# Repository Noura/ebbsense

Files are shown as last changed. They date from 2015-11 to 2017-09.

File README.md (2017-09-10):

# EBB Sense
  Controlling a wearable display using a bitalino EDA sensor

### Software
- Arduino Code

### Serial Graph for Debugging
- Graph the data from the arduino code running over Serial port
- Scale using up and down keys

### Hardware

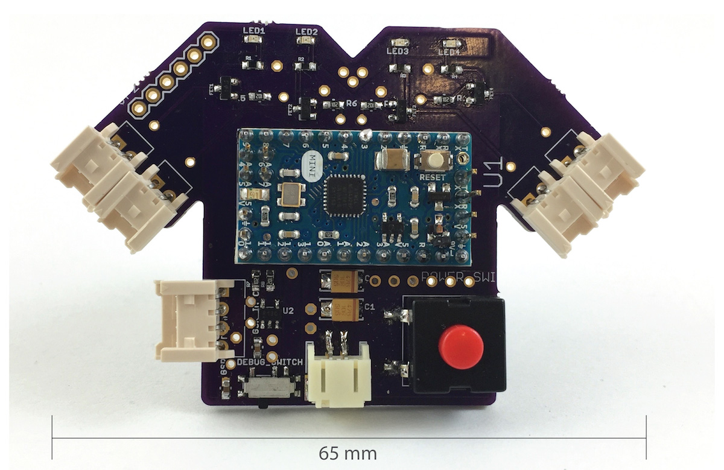
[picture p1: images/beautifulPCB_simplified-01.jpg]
Custom PCB


- Eagle schematic and board
- Current version is 2.1

### Shirt

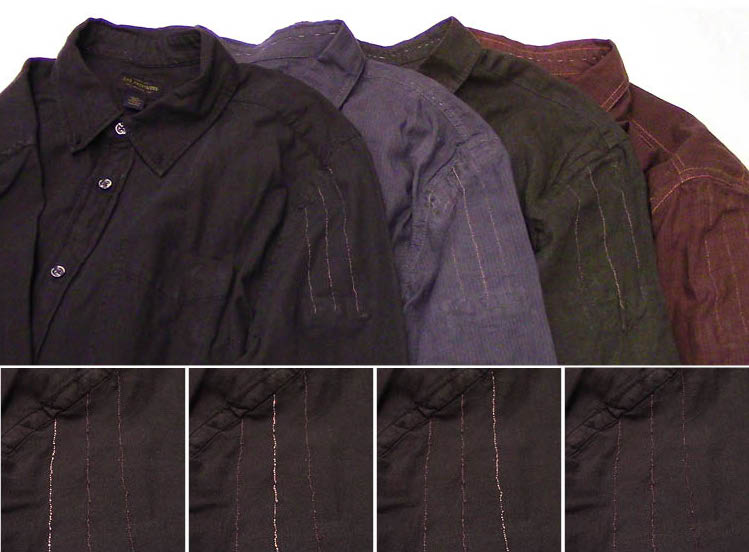
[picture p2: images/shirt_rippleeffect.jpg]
Shirt


Each pinstripe had about 2-7Ω resistance and received about 450mA from a 3.7V LiPo battery via an Adafruit Powerboost 5V regulator, switching on (100% duty cycle) or off (0%) with a transistor controlled by Arduino pins. Each pinstripe consists of a single conductive thread. Snaps on the inside of the shirt provided removable but secure electrical connections to the thread endpoints. A Bitalino skin conductance sensor was placed on the back of the left shoulder of the shirt to hide the sensor from public view and secure it within the shirt. 

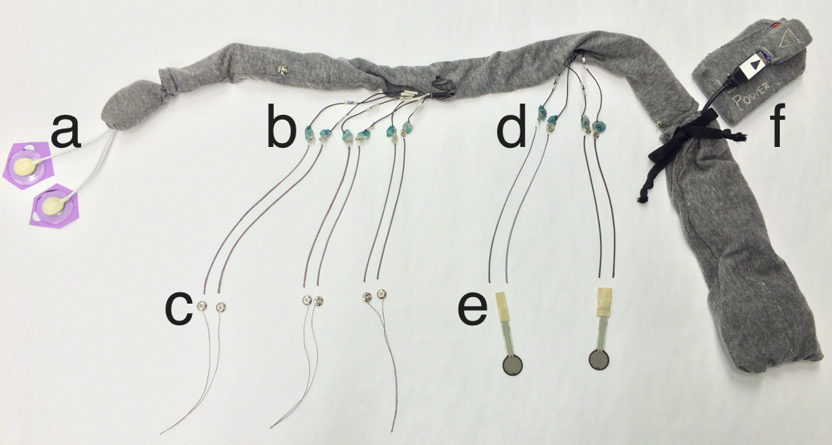
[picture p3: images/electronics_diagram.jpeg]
Electronics Physical Diagram


Fabric enclosures for electronics fit inside the shirt. (a) Skin conductance sensor with electrodes on colored paper for visibility. (b) Snaps connections to pinstripes. (c) Diagrammatic representation of pinstripes, which in actuality were sewn into shirt. (d) Snaps connections with FSRs for override on/off features. (e) Diagrammatic representation of FSRs, which in actuality were embedded in shirt seams. (f) PCB and battery, which were hidden in an interior shirt pocket.

---

### Team
- Noura Howell
- Laura Devendorf
- Rundong Tian
- Tomás Vega

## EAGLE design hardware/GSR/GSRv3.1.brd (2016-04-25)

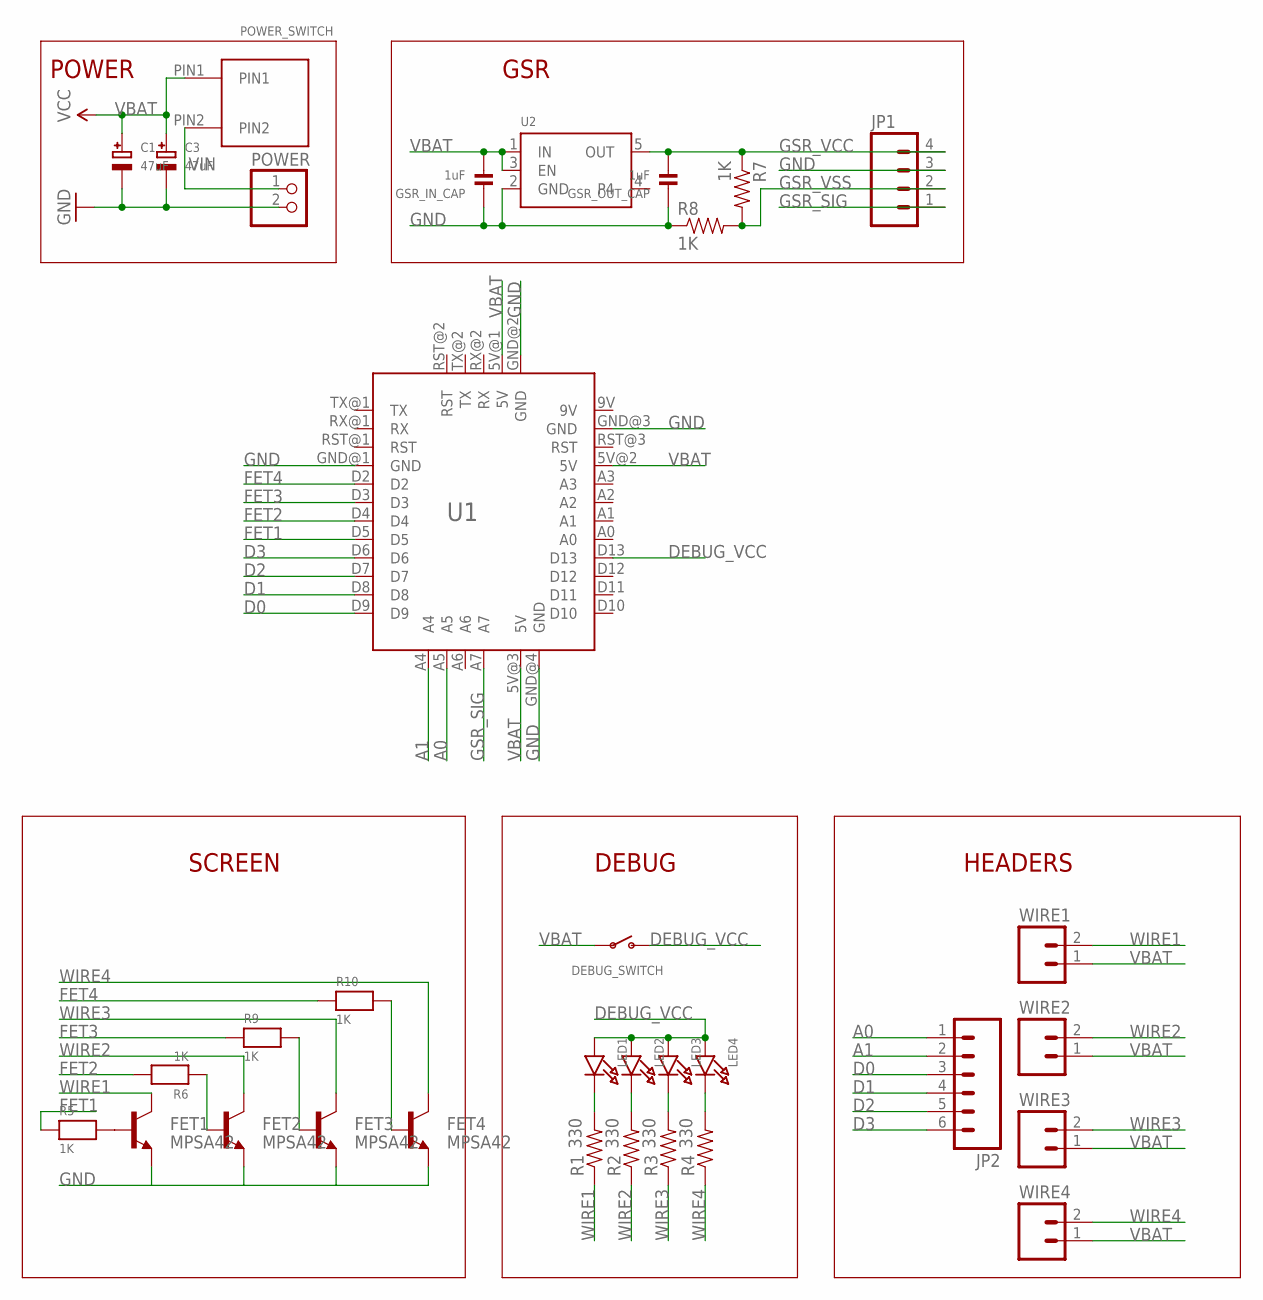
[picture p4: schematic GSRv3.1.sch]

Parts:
C1, C3: 47uF; EIA3528-21/B-W
DEBUG_SWITCH: SWITCH_SPST; SPST_SMT_19192
FET1, FET2, FET3, FET4: MPSA42; SOT23-3
GSR_IN_CAP: 1uF; 0603
GSR_OUT_CAP: 1uF; 0603
JP1: M04POLAR; MOLEX-1X4
JP2: M06SILK_FEMALE_PTH; 1X06
LED1, LED2, LED3, LED4: LED0603_NOOUTLINE; CHIPLED_0603_NOOUTLINE
POWER: JST_2PIN; JSTPH2
POWER_SWITCH: PUSH_BUTTON
R1, R2, R3, R4: 330; 0603-RES
R5, R6, R7, R8, R9, R10: 1K; 0603
U1: ARDUINO_MINI
U2: VREG_SOT23-5; SOT23-5
WIRE1, WIRE2, WIRE3, WIRE4: M02POLAR; MOLEX-1X2

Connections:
9V: U1.9V
A0: JP2.1, U1.A5
A1: JP2.2, U1.A4
D0: JP2.3, U1.D9
D1: JP2.4, U1.D8
D2: JP2.5, U1.D7
D3: JP2.6, U1.D6
DEBUG_VCC: DEBUG_SWITCH.C (S), LED1.A, LED2.A, LED3.A, LED4.A, U1.D13
FET1: R5.1, U1.D5
FET2: R6.2, U1.D4
FET3: R9.1, U1.D3
FET4: R10.1, U1.D2
GND: C1.-, C3.-, FET1.2 (E), FET2.2 (E), FET3.2 (E), FET4.2 (E), GSR_IN_CAP.1, GSR_OUT_CAP.1, JP1.3, POWER.2, R8.1, U1.GND@1 (GND), U1.GND@2 (GND), U1.GND@3 (GND), U1.GND@4 (GND), U2.2 (GND)
GSR_SIG: JP1.1, U1.A7
GSR_VCC: GSR_OUT_CAP.2, JP1.4, R7.1, U2.5 (OUT)
GSR_VSS: JP1.2, R7.2, R8.2
unnamed: LED1.C, R1.2
unnamed: LED2.C, R2.2
unnamed: LED3.C, R3.2
unnamed: LED4.C, R4.2
unnamed: FET1.1 (B), R5.2
unnamed: FET2.1 (B), R6.1
unnamed: FET3.1 (B), R9.2
unnamed: FET4.1 (B), R10.2
VBAT: C1.+, C3.+, DEBUG_SWITCH.B, GSR_IN_CAP.2, POWER_SWITCH.PIN1, U1.5V@1 (5V), U1.5V@2 (5V), U1.5V@3 (5V), U2.1 (IN), U2.3 (EN), WIRE1.1, WIRE2.1, WIRE3.1, WIRE4.1
VIN: POWER.1, POWER_SWITCH.PIN2
WIRE1: FET1.3 (C), R1.1, WIRE1.2
WIRE2: FET2.3 (C), R2.1, WIRE2.2
WIRE3: FET3.3 (C), R3.1, WIRE3.2
WIRE4: FET4.3 (C), R4.1, WIRE4.2

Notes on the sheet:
DEBUG
SCREEN
HEADERS
POWER
GSR

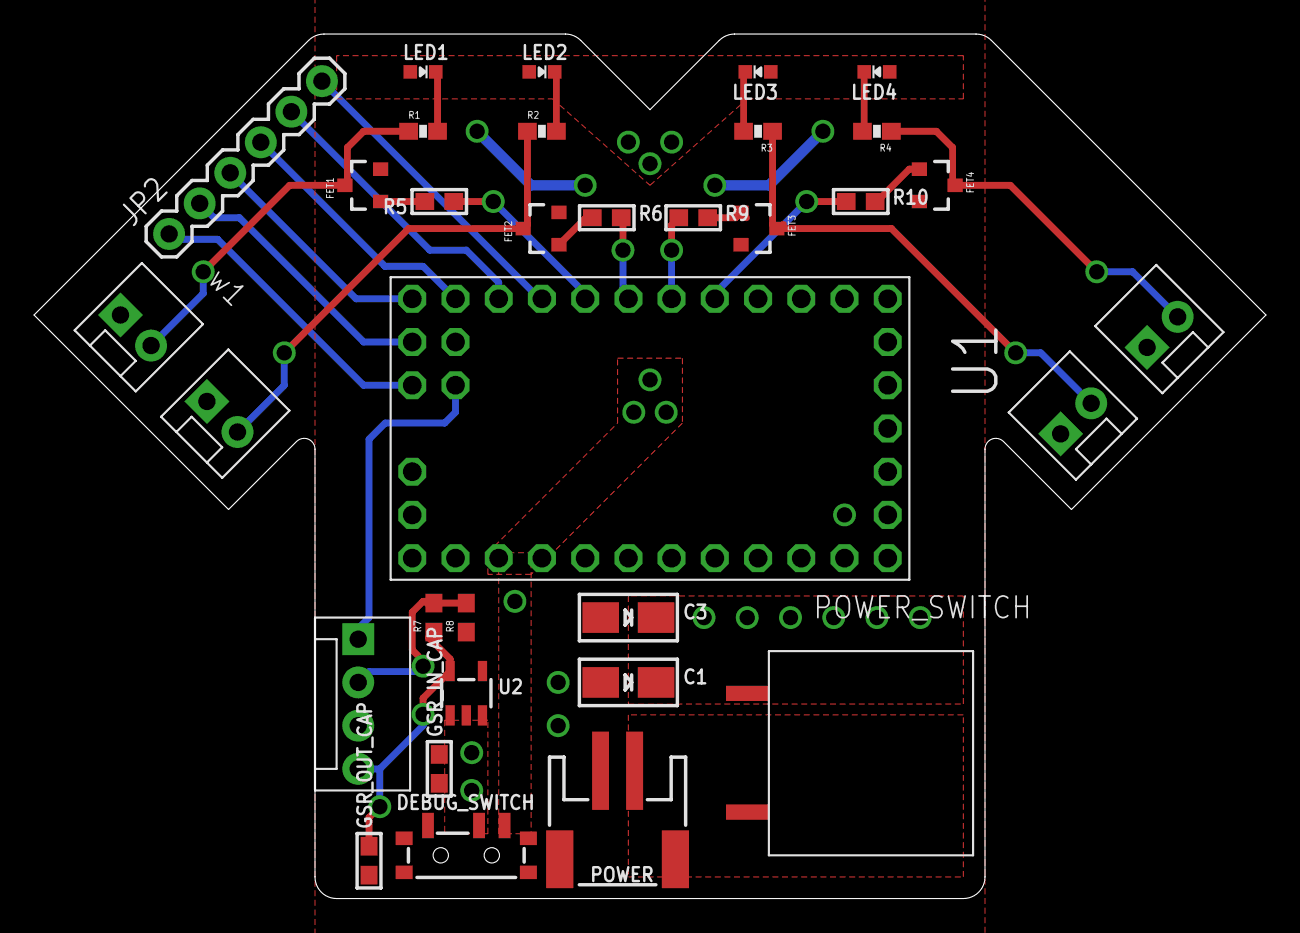
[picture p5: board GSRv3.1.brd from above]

Board: 2 copper layers, 72.4 x 50.8 mm, 33 parts (0 on the bottom side), 29 nets.

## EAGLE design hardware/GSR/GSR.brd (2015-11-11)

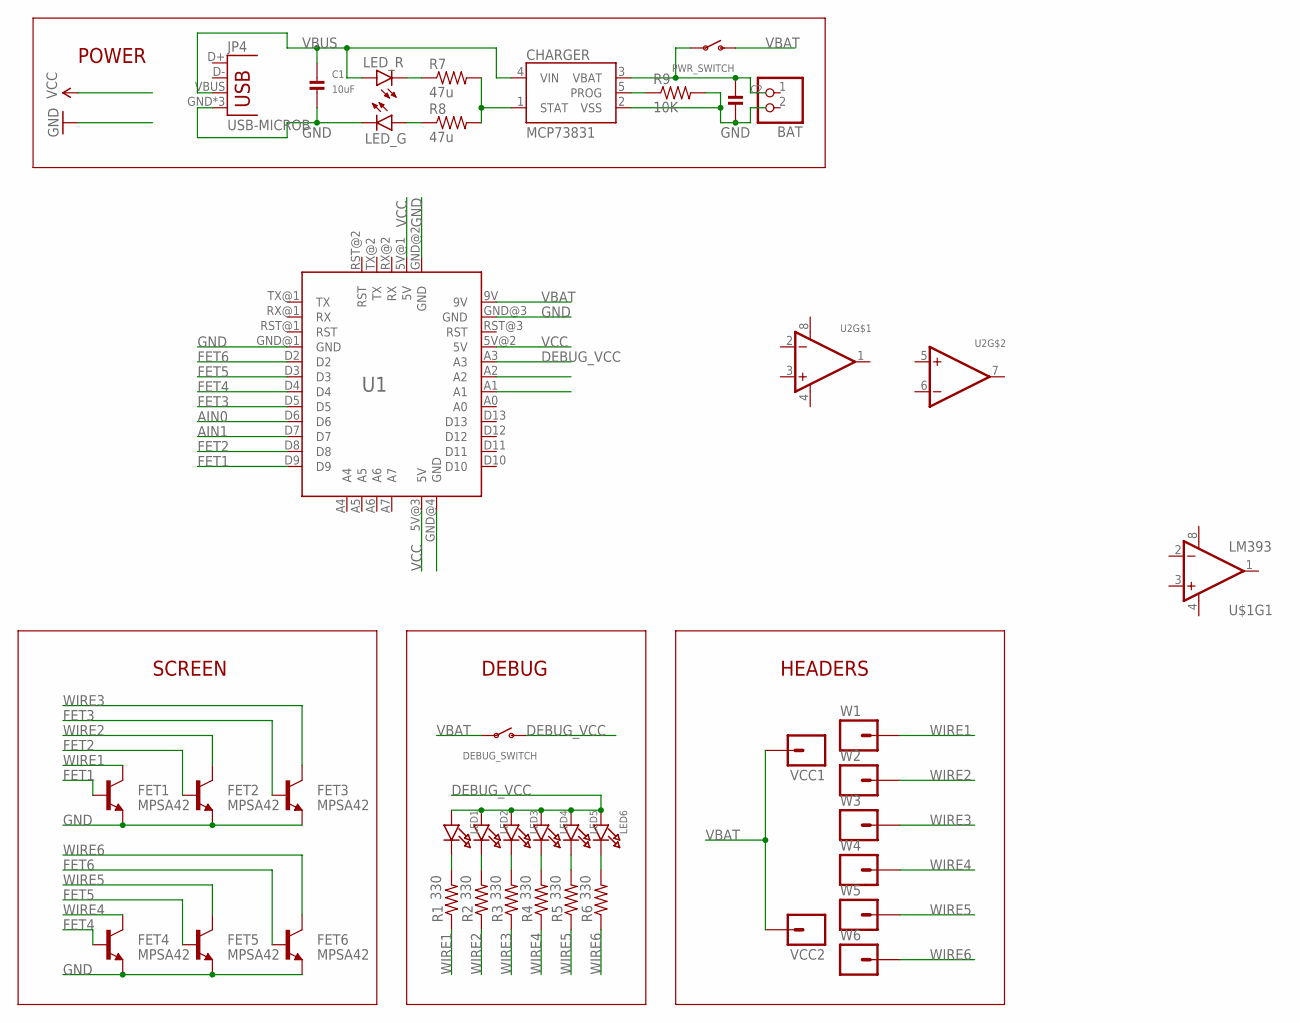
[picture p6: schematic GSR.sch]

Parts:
BAT: JST_2PIN-SMT; JST-PH-2-SMT
C1: 10uF; 0603
C2: CAP_CERAMIC0603; 0603
CHARGER: MCP73831; SOT23-5
DEBUG_SWITCH: SWITCH_SPST; SPST_SMT_19192
FET1, FET2, FET3, FET4, FET5, FET6: MPSA42; SOT23-3
JP4: USB-MICROB
LED1, LED2, LED3, LED4, LED5, LED6: LED0603_NOOUTLINE; CHIPLED_0603_NOOUTLINE
LED_G: LED0603; LED-0603
LED_R: LED0603; LED-0603
PWR_SWITCH: SWITCH_SPST; SPST_SMT_19192
R1, R2, R3, R4, R5, R6: 330; 0603-RES
R7, R8: 47u; 0603-RES
R9: 10K; 0603-RES
U1: ARDUINO_MINI
U2: OPAMP_DUALMSOP8_65; MSOP8_0.65MM
U$1: LM393; SO08
VCC1, VCC2: M01NOSILK-KIT; 1X01NS-KIT
W1, W2, W3, W4, W5, W6: M01NOSILK-KIT; 1X01NS-KIT

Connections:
AIN0: U1.D6
AIN1: U1.D7
DEBUG_VCC: DEBUG_SWITCH.C (S), LED1.A, LED2.A, LED3.A, LED4.A, LED5.A, LED6.A, U1.A3
FET1: FET1.1 (B), U1.D9
FET2: FET2.1 (B), U1.D8
FET3: FET3.1 (B), U1.D5
FET4: FET4.1 (B), U1.D4
FET5: FET5.1 (B), U1.D3
FET6: FET6.1 (B), U1.D2
GND: C1.2, C2.2, CHARGER.2 (VSS), FET1.2 (E), FET2.2 (E), FET3.2 (E), FET4.2 (E), FET5.2 (E), FET6.2 (E), JP4.GND, JP4.MT1 (GND), JP4.MT2 (GND), LED_G.C, R9.2, U1.GND@1 (GND), U1.GND@2 (GND), U1.GND@3 (GND), U1.GND@4 (GND)
unnamed: LED1.C, R1.2
unnamed: LED2.C, R2.2
unnamed: LED3.C, R3.2
unnamed: LED4.C, R4.2
unnamed: LED5.C, R5.2
unnamed: LED6.C, R6.2
unnamed: CHARGER.1 (STAT), R7.2, R8.2
unnamed: LED_G.A, R8.1
unnamed: LED_R.C, R7.1
unnamed: CHARGER.5 (PROG), R9.1
V+: U2.8 (V+), U$1.8 (V+)
V-: U2.4 (V-), U$1.4 (V-)
VBAT: DEBUG_SWITCH.B, PWR_SWITCH.C (S), U1.9V, VCC1.1, VCC2.1
VBAT_IN: C2.1, CHARGER.3 (VBAT), PWR_SWITCH.B
VBUS: C1.1, CHARGER.4 (VIN), JP4.VBUS, LED_R.A
VCC: U1.5V@1 (5V), U1.5V@2 (5V), U1.5V@3 (5V)
WIRE1: FET1.3 (C), R1.1, W1.1
WIRE2: FET2.3 (C), R2.1, W2.1
WIRE3: FET3.3 (C), R3.1, W3.1
WIRE4: FET4.3 (C), R4.1, W4.1
WIRE5: FET5.3 (C), R5.1, W5.1
WIRE6: FET6.3 (C), R6.1, W6.1

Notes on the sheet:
DEBUG
SCREEN
HEADERS
POWER

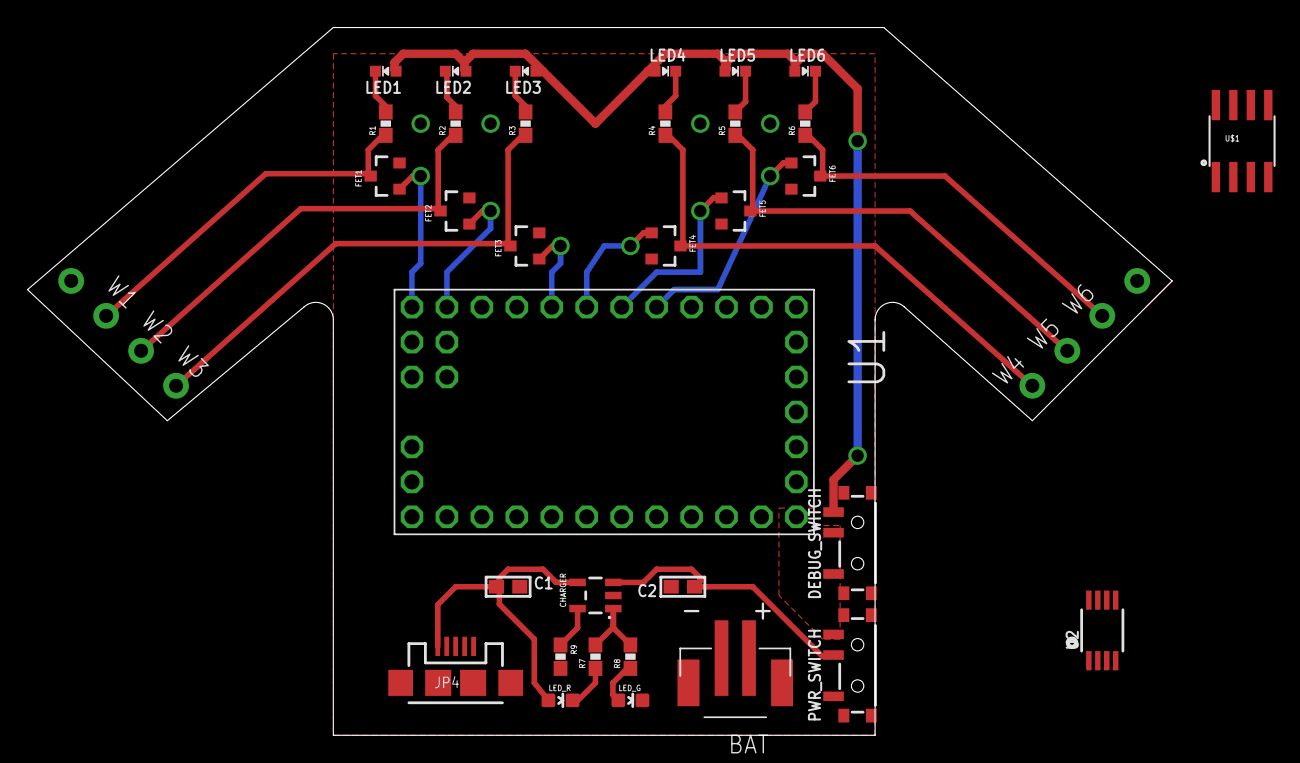
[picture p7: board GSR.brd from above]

Board: 2 copper layers, 83.2 x 51.4 mm, 41 parts (0 on the bottom side), 30 nets.

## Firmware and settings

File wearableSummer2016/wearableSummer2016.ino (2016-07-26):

/* Wearable Color-Changing Shirt for Summer 2016
   2016 Noura Howell
   
   This is intended to go with a shirt with a few color-changing threads. The
   wearer of the shirt also wears a Bitalino EDA sensor. All this is connected
   to our PCB which has an Arduino Mini running this sketch.
   
   When the wearer's EDA spikes, this "moment" is displayed by making the
   threads change color. First one thread changes color, then as it fades the
   next thread changes, and so on - a sort of "ripple effect" for each moment.
*/

#include <EDA.h>
#include <PrintArray.h>
#include <Threads.h>

/////////////////////////////////////////////////////////////////
// SETTINGS /////////////////////////////////////////////////////
// FOR LIGHT BROWN SHIRT ////////////////////////////////////////
/////////////////////////////////////////////////////////////////

// how many threads we are using
#define N_THREADS 3
// how long to display each moment for
// MOMENT_DT - threadPowerDurations[i] is how long thread_i has to cool off
#define MOMENT_DT 150000

// the pin the EDA sensor is connected to
#define edaSensorPin A7

// TODO the pin the FSR sensor is connected to
// TODO pressing this FSR forces a "moment"
#define fsrMomentOnPin A0
// the pin the FSR sensor is connected to
// TODO touching this FSR turns off the threads
#define fsrMomentOffPin A1
// readings greater than this means FSR is being touched
#define fsrThreshold 800

// all pins that the PCB has for thread outputs - some may be broken on this PCB
// TODO I think pin 2 is not even a PWM out
int allThreadPins[] = {5, 6, 3, 2};

// where threads are actually plugged in - these pins are working
int threadPins[] = {5, 6, 3};

// change pretty quickly, maybe don't leave on too long at this power level?
// third thread doesn't change as much in some environments.
// how much power each thread needs. depends on their length etc
// int threadPowerLevels[] = {30, 30, 30};
// how long (ms) each thread should get power for to change color
// unsigned long threadPowerDurations[] = { 10000, 10000, 10000 };

// change pretty quickly, maybe don't leave on too long at this power level?
// third thread needs a bit more power so here it's good
// int threadPowerLevels[] = {30, 30, 40};
// unsigned long threadPowerDurations[] = { 20000, 20000, 20000 };

// change very slowly, seems OK to leave it on for a pretty long while
// although it does get warm
//int threadPowerLevels[] = {15, 18, 20};
//unsigned long threadPowerDurations[] = { 120000, 120000, 120000 };

int threadPowerLevels[] = {35, 35, 35};
unsigned long threadPowerDurations[] = { 120000, 120000, 120000 };
///////////////////////////////

// EDA sensor & spike detection
EDA myEDASensor;

// threads controller
Threads myThreads;
// specify which threads we want to be on at any given time
bool threadsOn[N_THREADS];

// log when moments happen
unsigned long momentTimes[N_THREADS];

// temp variables for repeated use in loop()
int edaVal;
unsigned long t;
unsigned long dt;
int thread_index;
bool momentWasLogged;

/* TEST: working up to MAIN but using the Threads library and moments */

void setup() {
  Serial.begin(9600);
  
  // make sure ALL thread pins are off, even the ones we aren't using
  for (int i = 0; i < 4; i++) {
    analogWrite(allThreadPins[i], 0);
  }
  
  for (int i = 0; i < N_THREADS; i++) {
    // initialize all momentTimes to 0
    momentTimes[i] = 0;
    // initialize it so all threads should be off
    threadsOn[i] = false;
  }
  
  myThreads.init(N_THREADS, threadPins, threadPowerLevels, threadPowerDurations);
}

void loop() {
  Serial.println();
  
  t = millis();
  Serial.print("t: ");Serial.println(t);
  
  Serial.print("fsrON: ");Serial.println(analogRead(fsrMomentOnPin));
  Serial.print("fsrOFF: ");Serial.println(analogRead(fsrMomentOffPin));
  
  // if the EDA sensor has a peak, log that as a moment
  edaVal = analogRead(edaSensorPin);
  Serial.print("edaVal: ");Serial.println(edaVal);
  myEDASensor.update(edaVal);
  if ( myEDASensor.hasPeak() ) {
    Serial.println("EDA SENSOR PEAK");
    momentWasLogged = logMoment(t);
    Serial.print("momentWasLogged: ");Serial.println(momentWasLogged);
  }
  
  // if the fsrMomentOn is pressed, log that as a moment
  if (analogRead(fsrMomentOnPin) > fsrThreshold) {
    Serial.println("FSR MOMENT ON PRESS");
    momentWasLogged = logMoment(t);
    Serial.print("momentWasLogged: ");Serial.println(momentWasLogged);
  }
  
  // if the fsrMomentOff is pressed, remove all moments
  if (analogRead(fsrMomentOffPin) > fsrThreshold) {
    Serial.println("FSR MOMENT OFF PRESS");
    for (int i = 0; i < N_THREADS; i++) {
      momentTimes[i] = 0;
    }
  }
  
  // deciding which threads should be on
  for (int i = 0; i < N_THREADS; i++) {
    // refresh all threads to be off for this loop
    threadsOn[i] = false;
  }
  for (int i = 0; i < N_THREADS; i++) {
    // check each moment time.
    // if there wasn't a moment, do nothing
    if (momentTimes[i] == 0) continue;
    // how long ago the moment happened determines which thread should be on to
    // display that moment
    dt = abs(t - momentTimes[i]);
    thread_index = dt / MOMENT_DT;
    if (thread_index < N_THREADS) {
      threadsOn[thread_index] = true;
    }
  }
  // threads controller will make sure the threads we specify are on
  myThreads.update(threadsOn);
  
  Serial.print("momentTimes: ");
  PrintArray::printArrayUnsignedLong(momentTimes, N_THREADS);
  Serial.print("threadsOn: ");
  PrintArray::printArrayBool(threadsOn, N_THREADS);
  
  delay(500);
}

bool logMoment(unsigned long t) {
  // if we already logged the moment, don't log it again
  if ( momentTimes[0] != 0 && abs(t - momentTimes[0]) < MOMENT_DT ) {
    return false;
  }
  
  // OK we know it's a distinct moment that we should record in our FIFO array
  for (int i = N_THREADS - 1; i >= 1; i--) {
    momentTimes[i] = momentTimes[i-1];
  }
  momentTimes[0] = t;
  return true;
}

/* TEST: all 4 debug LEDs on the PCB 
   NOTE: make sure the debug switch is on so the LEDs can light up

void setup() {
  Serial.begin(9600);
  for (int i = 0; i < 4; i++) {
    analogWrite(allThreadPins[i], 0);
  }
}

void loop() {
  for (int i = 0; i < 4; i++) {
    Serial.print("\nturning on pin ");Serial.println(allThreadPins[i]);
    analogWrite(allThreadPins[i], 255);
    delay(1000);
    Serial.println("turning that pin off");
    analogWrite(allThreadPins[i], 0);
  }
}*/

/* OLD MAIN: for turning one thread on and off
void setup() {
  Serial.begin(9600);
  pinMode(threadPin, OUTPUT);
  threadTimeOn = 0;
  threadOn = false;
  pinMode(buttonPin, INPUT);
  digitalWrite(threadPin, 0);
}

void loop() {
  int sensorRaw = myEDA.update();
  
  // the button lets the user force the thread to turn on
  int buttonVal = digitalRead(buttonPin);
  
  // TODO fsrOff lets the user force the threads to turn off
  fsrOffVal = analogRead(fsrOffPin);
  
  if (hasPeak() || buttonVal > 0) {
    // sending data to Processing sketch which graphs it
    Serial.print("MARK");Serial.print(",");
    if (!threadOn) {
      analogWrite(threadPin, 255);
      threadTimeOn = millis();
      threadOn = true;
    }
  } else {
    if (threadOn && millis() - threadTimeOn > threadStayOnFor) {
      analogWrite(threadPin, 0);
      threadOn = false;
    }
  }
  
  // sending data to Processing sketch which graphs it
  Serial.print(sensorRaw);Serial.print(",");
}*/

/* TEST: reading fsrOff
void setup () {}

void loop() {
  fsrOffVal = analogRead(fsrOffPin);
  Serial.println(fsrOffVal);
  if (fsrOffVal > fsrOffThreshold) {
    Serial.println("TOUCH"); 
  }
  delay(100);
}*/

/* TEST: powering the threads
void setup () {}

void loop() {
  analogWrite(5, 255);
}*/

/* TEST: EDA.h
void setup() {
  Serial.begin(9600);
}

void loop() {
  int edaVal = analogRead(edaSensorPin);
  myEDA.update(edaVal);
  Serial.print(edaVal);Serial.print(",");
  if ( myEDA.hasPeak() ) {
    Serial.print("MARK");Serial.print(","); 
  }
}*/

/* TEST: reading edaSensorPin directly
void setup() {
  Serial.begin(9600); 
}

void loop() {
  int edaVal = analogRead(edaSensorPin);
  Serial.print(edaVal);Serial.print(",");
}*/

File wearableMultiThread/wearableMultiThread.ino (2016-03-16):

/* Comment by Noura on March 15, 2016:
I think this is when I was still trying to program it to maybe 
control multiple threads. This added the complication of switching
the power supply to each thread that was currently "on". I am 
not sure but I wonder if this created a bug. So, unless I am 
definitely using more than one thread, I would just use the 
wearabeOneThread sketch instead. It has one thread hard coded
so the code is a bit simpler */


// SETTINGS ///////////////////
// the pin the GSR sensor is plugged into
#define sensorPin A5
// the number of previous filtered GSR readings to store
#define N 100
// sample rate of taking GSR readings in Hz
#define sampleRate 20
// You should think about the sampleRate and N carefully.
// For example if the sampleRate is 20 and N is 100, then we are storing the previous
// 100 / 20 = 5 seconds worth of data. This is the time scale over which we will compute
// the average and standard deviation, which are used for spike detection.

// the number of threads on the wearable
#define NTHREADS 1
// where threads are plugged in
int threadPin[NTHREADS] = {5};
// how much power you think each thread needs. depends on their length etc
int threadPower[NTHREADS] = {255};
// how long (ms) a thread should stay on for before turning off
#define threadStayOnFor 60000
///////////////////////////////

// NOTE
// throughout, "activated" or "on" for threads is used interchangeably
// and "deactivated" or "off" for threads is used interchangeably
// but "supplying power" to a thread is different, because all the
// threads that are "on" take turns getting supplied power in order
// to accommodate the amount of current the battery can supply.

// Low pass bessel filter order=1 alpha1=0.02 samplerate=20
// designed at http://www.schwietering.com/jayduino/filtuino/
// http://www.schwietering.com/jayduino/filtuino/index.php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
class filter
{
  public:
    filter()
    {
      v[0]=0.0;
    }
  private:
    float v[2];
  public:
    float step(float x) //class II 
    {
      v[0] = v[1];
      v[1] = (5.919070381841e-2 * x)
             + (  0.8816185924 * v[0]);
      return (v[0] + v[1]);
    }
};

filter myFilter;

int sensorRaw;
int sensorFilteredNew;
int sensorFiltered[N];

int samplePeriod = 1000 / sampleRate;

// the time at which a thread was activated.
// threads get deactivated after threadStayOnFor milliseconds
long threadTimeOn[NTHREADS];
// whether each thread is currently activated or not
bool threadOn[NTHREADS];

void setup() {
  Serial.begin(9600);
  for (int i = 0; i < NTHREADS; i++) {
    pinMode(threadPin[i], OUTPUT);
    threadTimeOn[i] = 0;
    threadOn[i] = false;
  }
}

void loop() {
  sensorRaw = analogRead(sensorPin);
  sensorRaw = min(sensorRaw, 1023);
  sensorRaw = max(sensorRaw, 0);
  sensorFilteredNew = myFilter.step(sensorRaw);
  addToArray(sensorFilteredNew);
  
  if (hasPeak()) {
    // sending data to Processing sketch which graphs it
    Serial.print("MARK");Serial.print(",");
    // turn on a thread to show this peak
    activateThread();
  }
  // sending data to Processing sketch which graphs it
  Serial.print(sensorFilteredNew);Serial.println(",");
  
  // keeps track of giving power to the threads that are
  // currently on, as well as turning threads off after
  // stayOnFor milliseconds since the thread came on
  updateThreads();

  // wait this much time so that we regularly sample
  // the GSR sensor
  delay(samplePeriod);
}

// which thread to activate this time. should only be used by activateThread()
int whichThread = 0;
void activateThread() {
  // you have to do these three things to turn a thread "on"
  threadOn[whichThread] = true;
  threadTimeOn[whichThread] = millis();
  
  // choosing which thread to activate next
  // this cycles through all the available threads
  whichThread += 1;
  whichThread %= NTHREADS;
}

// which thread last received power. should only be used by activateThreads()
int threadLastPowered = 0;
void updateThreads() {
  // 1. makes all the activated threads take turns getting power from
  //    the battery. each time updateThreads() is called, it chooses
  //    a different activated thread to receive power.
  // 2. turns off threads after stayOnFor ms since thread came on.
  
  // the last thread to get power already got some power, so its turn
  // is over. stop giving it power.
//  Serial.println();Serial.print(threadPin[threadLastPowered]);Serial.println(" off");
//  analogWrite(threadPin[threadLastPowered], 0);
  
  // choose the next thread to give power to. start by looking at the
  // the next thread right after threadLastPowered, and then keep
  // checking each thread one by one until we find one that is on.
  // once we find one that is on, we can give that thread power and
  // stop looking/break out of the for loop
  int startThread = (threadLastPowered + 1) % NTHREADS;
  for (int j = 0; j < NTHREADS; j++) {
    int i = (startThread + j) % NTHREADS;
    if (threadOn[i]) {
      //Serial.println();
      Serial.print("\npowering thread at pin: ");Serial.println(threadPin[i]);
      analogWrite(threadPin[i], threadPower[i]);
      threadLastPowered = i;
      break;
    } else {
      // also just make sure any "off" pins are not getting power.
      // not sure if this is necessary here?
      analogWrite(threadPin[i], 0);
    }
  }
  
  // go through all the threads and see which have been on for long
  // enough that it is time to turn them off. also turn off the
  // corresponding LED for that thread.
  for (int i = 0; i < NTHREADS; i++) {
    if (threadOn[i] && millis() - threadTimeOn[i] > threadStayOnFor) {
      threadOn[i] = false;
    }
  }
}

void addToArray(int x) {
  // index 0 holds the most recent value
  // index N-1 holds the oldest value
  for (int i = N - 1; i >= 1; i--) {
    sensorFiltered[i] = sensorFiltered[i-1];
  }
  sensorFiltered[0] = x;
}

bool hasPeak() {
  // calculate the average
  float avg = 0;
  for (int i = 0; i < N; i++) {
    avg += sensorFiltered[i];
  }
  avg /= N;

  // calculate the standard deviation
  float std = 0;
  for (int i = 0; i < N; i++) {
    std += pow(sensorFiltered[i] - avg, 2);
  }
  std = sqrt(std / N);
  
  // if the current value is more than a standard deviation above the mean,
  // then that counts as a peak. also make sure that the current value is
  // more than 25 above the mean, in case there is just some noise in a
  // pretty flat signal
  if (sensorFiltered[0] - avg > std &&
      sensorFiltered[0] - avg > 50 ) {
    return true;
  } else {
    return false;
  }
}

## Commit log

2015-10-29 adding basic filter code and processing serial graph
2015-10-29 adding link to the filter library we are using
2015-10-30 changing to a different low pass filter with a cutoff around 0.4 Hz, and getting the serial graph to mark lines to show the peaks
2015-11-01 changed to doing spike detection based on average and standard deviation. when the current value is more than 1 standard deviation away from the average, that counts as a spike.
2015-11-01 changed the graphing so that it only draws a point when there is a new point coming in, rather than every time processing calls the draw function repeatedly. also fixed the way we were drawing marks 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
    [serial_graph.pde]
2015-11-03 trying out using a class to control the threads.
2015-11-03 decided not to use a class to control the threads individually. it helps for each thread to know about each other so they don't all try to draw power at the same time.
2015-11-04 thread management
2015-11-04 thread controls works for any number of output pwm pins now
2015-11-04 calibrating to the triangle we have
2015-11-05 replaced NPINS with NTHREADS for clarity
    [wearable.ino]
2015-11-05 when in debug mode, show LEDs going on / off corresponding to when threads are activated.
2015-11-09 added hardware and updated readme
    [GSR.brd, GSR.sch, GSRv2.1.brd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]
2015-11-11 better printing of serial ports list in processing sketch
2015-11-11 messing with threads settings
2015-11-11 debug mode and capping the filtered gsr values and a minimum threshold for what counts as a peak
2015-11-11 the code for the PCB is slightly different than the code for the breadboard arduino so they are diferent sketches now
2015-12-08 tweaking calibration
2015-12-08 wearableOneThread is a simplified version for when there is only one thread. less code is better
2016-03-09 changing the thread on time to 3 minutes
2016-03-09 second serial graph monitor is good for watching 2 prototypes simultaneously
2016-03-16 added button. pressing button forces peak, forcing power to thread.
2016-03-16 upped the peak threadshold. peaks must involve a GSR increase of at least 50 now, whereas before it was 25. hopefully this will solve an issue where what i think is some slight electrical noise (poss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
    [wearableOneThread.ino]
2016-03-31 changing sensor pin to A5
2016-06-23 printing raw sensor value instead of filtered sensor value
2016-06-23 code for the SmarTee PCB in summer 2016. adapted to have more features than previous iterations
2016-06-28 it activates each thread in turn now when a Moment (caused by an EDA spike or touching one of the FSR sensors) is logged
2016-06-29 turning off ALL thread pins at setup, not just the thread pins we are currently using.
2016-07-12 updating pins and thread power and timing settings. adding comments
2016-07-26 upping power settings at the last minute for the pilot study
2016-07-26 adding a print statement for edaVal
2017-09-10 adding pcb image to github

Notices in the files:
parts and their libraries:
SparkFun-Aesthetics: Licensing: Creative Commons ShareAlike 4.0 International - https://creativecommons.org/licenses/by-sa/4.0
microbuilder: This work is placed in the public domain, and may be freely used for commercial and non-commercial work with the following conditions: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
